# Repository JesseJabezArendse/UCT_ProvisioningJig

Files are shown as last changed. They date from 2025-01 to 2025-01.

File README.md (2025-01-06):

# UCT Provisioning Jig

This repository contains all resources and guides for the UCT Provisioning Jig.

---

### [Raspberry Pi Code/](https://github.com/JesseJabezArendse/UCT_ProvisioningJig/tree/main/Raspberry%20Pi%20Code)
This directory contains the main source code for the Provisioning Jig. 
It includes python scripts for hardware interaction and device programming.

### [PCBs/](https://github.com/JesseJabezArendse/UCT_ProvisioningJig/tree/main/PCB)
Schematics and PCB layouts for the Provisioning Jig and UCT Debugger v2.1.

### [Enclosure/](https://github.com/JesseJabezArendse/UCT_ProvisioningJig/tree/main/Enclosure)
Solidworks files, gcode and Assembly Guidelines for the Enclosure of the Provisioning Jig.

### [Documentation](https://github.com/JesseJabezArendse/UCT_ProvisioningJig/tree/main/Provisioning%20Jig%20v3%20Documentation.pdf)
Guidelines and specifications for using and modifying the Provisioning Jig.

---

## How to use the Provisioning Jig

1. Write the ProvisioningJig_V2J45.IMG file onto a 16GB SD Card using [Win32DiskImager](https://win32diskimager.org/).
2. 3D print the enclosure using the provided [gcode files](https://github.com/JesseJabezArendse/UCT_ProvisioningJig/tree/main/Enclosure/Enclosure%20gcode) and assemble according to the [guide](https://github.com/JesseJabezArendse/UCT_ProvisioningJig/blob/main/Enclosure/Assembly%20Guide.docx).

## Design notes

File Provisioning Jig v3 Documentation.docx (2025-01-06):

# Provisioning Jig v3 Documentation

Project by Jesse Jabez Arendse
Project for UCT EEE Department - Robyn Verrinder & Justin Pead

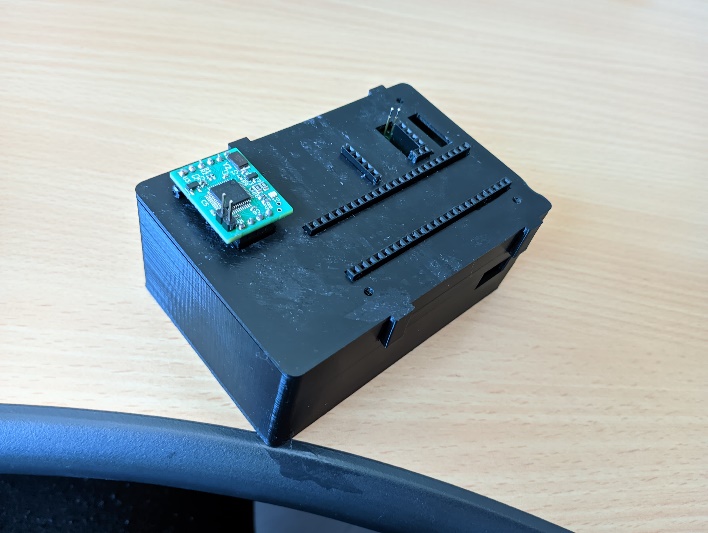
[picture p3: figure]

Host Machine Details:
Raspberry Pi 3B+ with Raspberry Pi OS 64-bit, with 16GB SD Card, SSH and VNC enabled

Username: ProvisioningJig
Password: ProvisioningJig
Hostname: raspberrypi

System Routine:

- On power up, LEDs are lit, indicating that the Pi is still booting up
- Once script starts, STLink is enumerated and LEDs pulse periodically, indicating the Jig is ready (idle mode)
- Plug either device in, orange LED lights up, indicating a device is detected
- Device is provisioned, indicated by STLink LED flashing red-blue (new) or red-green (old)
- Green LED is lit, indicating provisioning is successful and device can be removed

(If STLink LED stopped flashing and no LEDs are lit, provisioning failed, try again or device is faulty)

System Functions:

- Auto login and run provisioning script on startup
- Automatically detect which device is plugged in, and the version
- Flash the device via SWD, with its specific binary file
- Upgrade the STLink to a recent usable version, this step needed to be done with the STSW-LINK007 software package, but has been eliminated details found in the project report

For updates / reproduction:

- main script is located at /Desktop/ProvisioningJig_Code/newMain.py
- binary file selection can be done from the telnet_commands.py file
- use Win32DiskImager to create an .img of the ProvisioningJig’s SD Card, and then PiShrink to compress it (optional, but saves a few GB and time)
- use Win32DiskImager to flash the desired .img file to an SD Card
- assemble the Jig according to the assembly guide

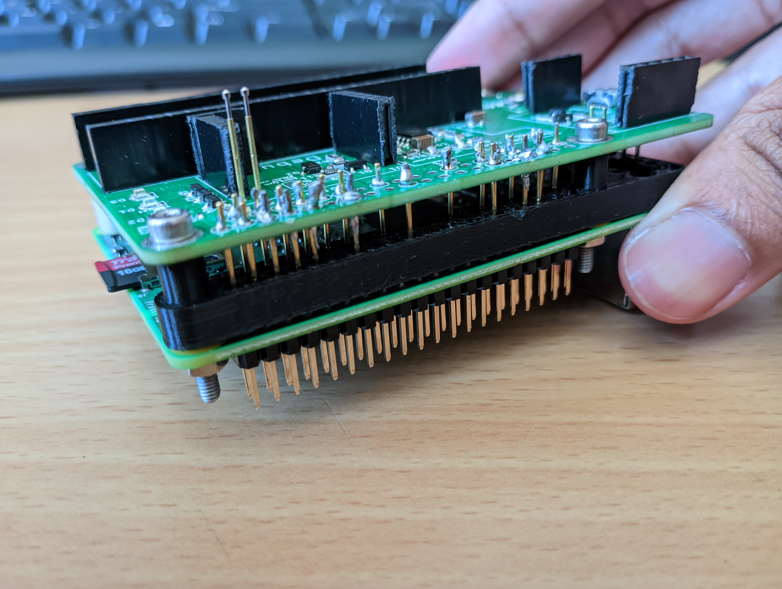
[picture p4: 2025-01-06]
pogos.jpg

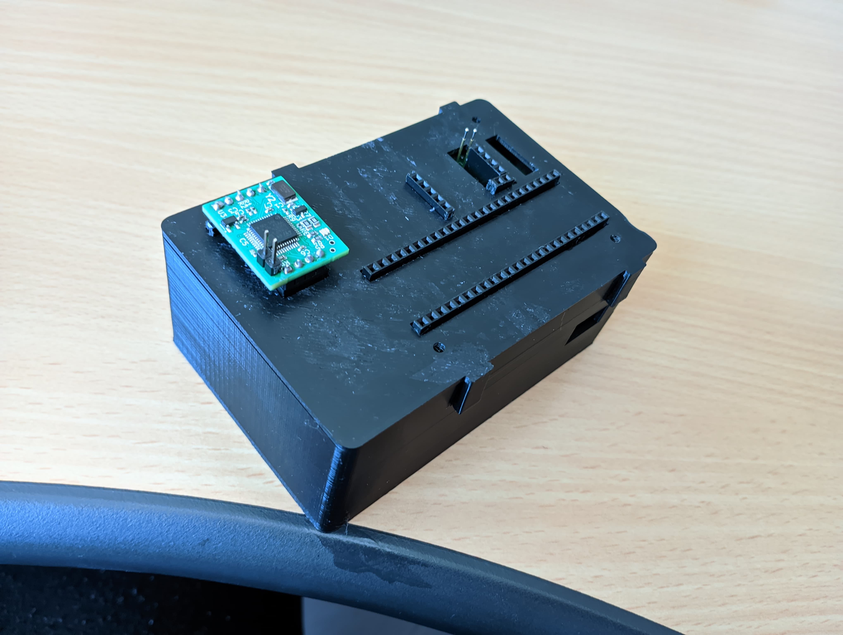
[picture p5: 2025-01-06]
main.jpg

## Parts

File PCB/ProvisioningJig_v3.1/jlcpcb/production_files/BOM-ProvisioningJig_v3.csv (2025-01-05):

Comment | Designator | Footprint | LCSC | Quantity
100u | C7,C9 | C_1206_3216Metric | C15008 | 2
AO3401A | Q2,Q6,Q8 | SOT-23 | C15127 | 3
10k | R12,R13,R17,R18 | R_0805_2012Metric | C17414 | 4
100k | R1,R10,R21,R22,R24,R25,R26,R27,R5,R6,R7,R9 | R_1206_3216Metric | C17900 | 12
1k | R11,R14,R16,R20,R3,R8 | R_0603_1608Metric | C21190 | 6
S8050_SMD | Q1,Q3,Q4,Q5,Q7,Q9 | SOT-23 | C2146 | 6
Yellow | D1,D2 | D_0805_2012Metric | C2296 | 2
Green | D3 | D_0805_2012Metric | C2297 | 1
100 | R15,R19,R2,R23,R4 | R_0402_1005Metric | C25076 | 5
100n | C10,C8 | C_0402_1005Metric | C307331 | 2
Target Button | SW1,SW2 | SW_SPST_TL3342 | C318884 | 2
USB for Debugger | J1,J5 | USB_Conn_JLC_LCSC_C404969 | C404969 | 2
LM393 | U5 | SOIC-8-1EP_3.9x4.9mm_P1.27mm_EP2.29x3mm | C7955 | 1
Target | U3 | STM32F051C6T6 |  | 1
New Version Debugger | U1 | STLINK_UCT |  | 1
ST-Link | U2 | STLINK_UCT |  | 1
POGO USB2- | J7 | P702200045 |  | 1
POGO USB2+ | J6 | P702200045 |  | 1
POGO USB1- | J4 | P702200045 |  | 1
POGO USB1+ | J3 | P702200045 |  | 1
Raspberry_Pi_2_3 | J2 | RASPBERRY_PI_3B |  | 1

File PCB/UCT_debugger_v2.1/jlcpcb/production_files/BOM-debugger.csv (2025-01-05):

Comment | Designator | Footprint | LCSC
X50328MSB2GI | Y2 | RESC5032X135N | C115962
100n | C5,C6,C7 | C_0402_1005Metric_Pad0.74x0.62mm_HandSolder | C1525
10k | R7,R8 | R_0805_2012Metric | C17414
S8050_SMD | Q1 | SOT-23 | C2146
150R | R4,R5,R6 | R_0603_1608Metric | C22808
100 | R3 | R_0402_1005Metric | C25076
1k5 | R1,R9 | R_0402_1005Metric_Pad0.72x0.64mm_HandSolder | C25867
LED_Dual_AKAK | D1 | DUAL_LED_COM_CATH_0606 | C2827309
10p | C1,C2 | C_0402_1005Metric_Pad0.74x0.62mm_HandSolder | C32949
2k | R2 | R_0402_1005Metric_Pad0.72x0.64mm_HandSolder | C4109
1u | C3,C4 | C_0402_1005Metric_Pad0.74x0.62mm_HandSolder | C52923
XC6206PxxxMR | U3 | SOT-23-3 | C5446
STM32F103CBTx | U4 | LQFP-48_7x7mm_P0.5mm | C8304

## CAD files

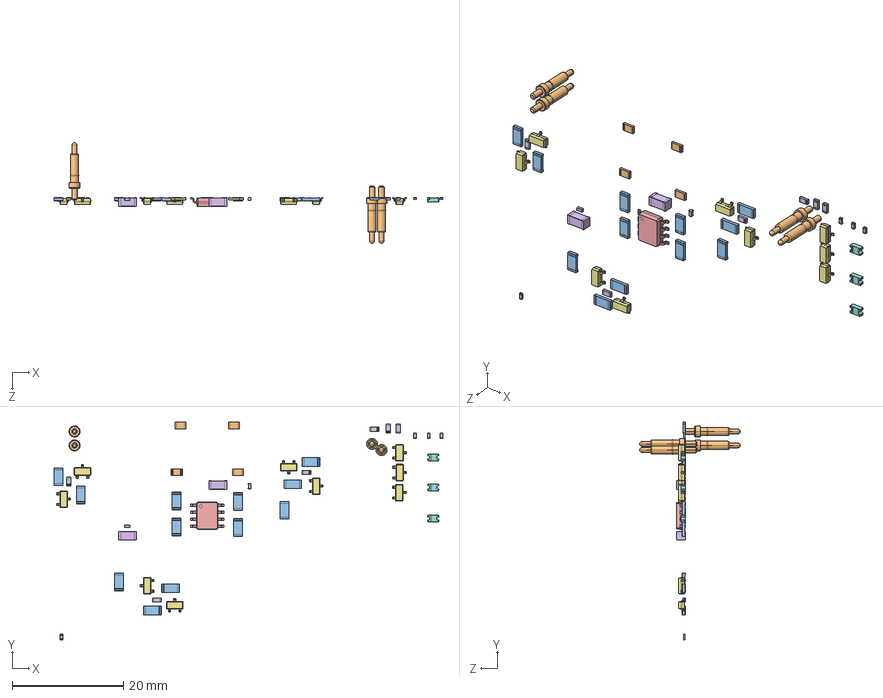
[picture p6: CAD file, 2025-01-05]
Enclosure/Solidworks Model/ProvisioningJig_Board.SLDASM
69.9 x 39.1 x 18.1 mm
R_0603_1608Metric-0.step x 6
R_0805_2012Metric-1.step x 4
R_1206_3216Metric-2.step x 12
R_0402_1005Metric-3.step x 5
SOIC-8-1EP_3.9x4.9mm_P1.27mm_EP2.29x3mm-4.step
C_1206_3216Metric-5.step x 2
SOT_23.step x 9
D_0805.step x 3
C_0402_1005Metric-7.step x 2
P70-2200045-8.step x 4

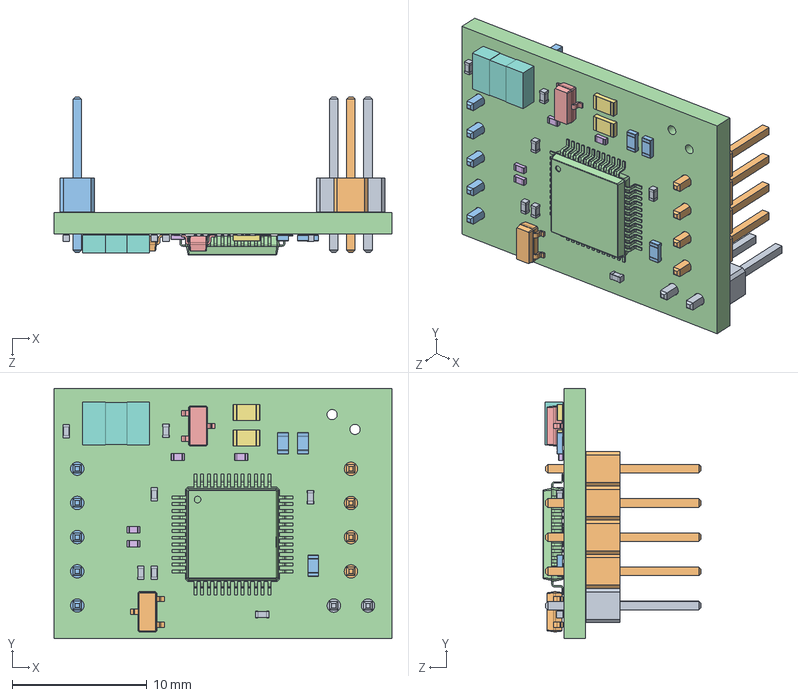
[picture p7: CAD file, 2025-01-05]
Enclosure/Solidworks Model/New_Debugger.SLDASM
25.1 x 18.6 x 11.7 mm
C_0402_1005Metric-7.step x 7
SOT-23-3-1.step
R_0603_1608Metric-0.step x 3
LQFP_48_7x7mm_P05mm.step
SOT_23.step
R_0402_1005Metric-3.step x 4
R_0805_2012Metric-1.step x 2
ASSEMBLY.step
PinHeader_1x02_P254mm_Vertical.step
PinHeader_1x04_P254mm_Vertical.step
PinHeader_1x05_P254mm_Vertical.step
debugger_PCB.step

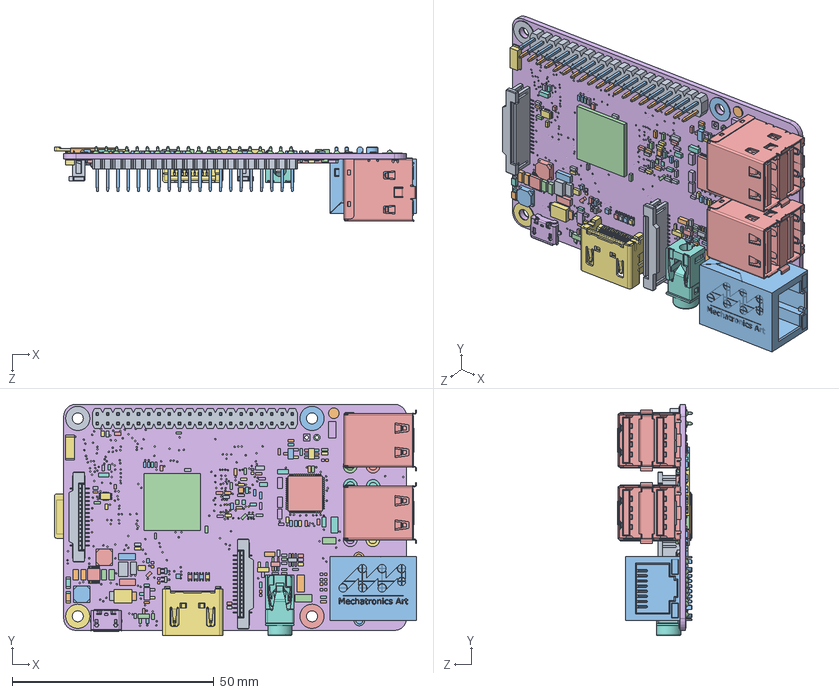
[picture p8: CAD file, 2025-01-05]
Enclosure/Solidworks Model/Raspberry Pi 3.SLDASM
89.6 x 57.3 x 18.6 mm
Raspberry Pi 3157
Raspberry Pi 3242 x 20
Raspberry Pi 3266 x 20
raspberry_pi_3(bar_180_2x20)
MOLEX_672983090 x 2
molex_0473460001
molex_0471510001
PJ-322
te_1-1734248-5 x 2
MOLEX_1040310811
raspberry_pi_B_(RJ45)
Raspberry Pi 312
Raspberry Pi 314
Raspberry Pi 3172
Raspberry Pi 3173
Raspberry Pi 3174
Raspberry Pi 3175
Raspberry Pi 3176
Raspberry Pi 3177
Raspberry Pi 3178
Raspberry Pi 3179
Raspberry Pi 3180
Raspberry Pi 3181
Raspberry Pi 3182
Raspberry Pi 3183
Raspberry Pi 3184
Raspberry Pi 3185
Raspberry Pi 3186
Raspberry Pi 3187
Raspberry Pi 3188
Raspberry Pi 3189
Raspberry Pi 3190
Raspberry Pi 3191
Raspberry Pi 3192
Raspberry Pi 3193
Raspberry Pi 3194
Raspberry Pi 3195
Raspberry Pi 3196
Raspberry Pi 3197
Raspberry Pi 3198
Raspberry Pi 3199
Raspberry Pi 3200
Raspberry Pi 3201
Raspberry Pi 3202
Raspberry Pi 3203
Raspberry Pi 3204
Raspberry Pi 3205
Raspberry Pi 3206
Raspberry Pi 3207
Raspberry Pi 3208
Raspberry Pi 3209
Raspberry Pi 3210
Raspberry Pi 3211
Raspberry Pi 3212
Raspberry Pi 3213
Raspberry Pi 3214
Raspberry Pi 3215
Raspberry Pi 3216
Raspberry Pi 3217
Raspberry Pi 3218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

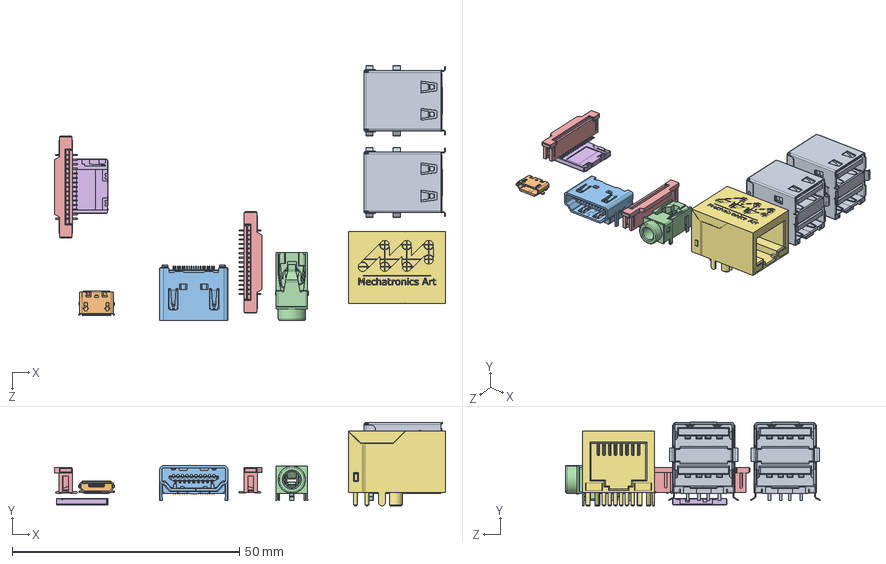
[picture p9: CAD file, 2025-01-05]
Enclosure/Solidworks Model/Rpi components/RPi3_ModelB v1.sldasm
86.1 x 18.5 x 56.1 mm
MOLEX_672983090 x 2
molex_0473460001
molex_0471510001
PJ-322
te_1-1734248-5 x 2
MOLEX_1040310811
raspberry_pi_B_(RJ45)

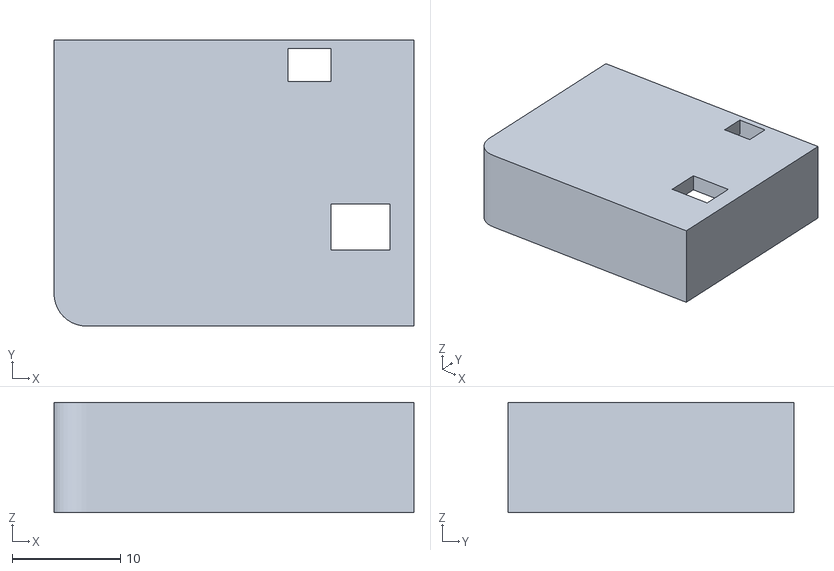
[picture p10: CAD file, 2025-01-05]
Enclosure/Enclosure gcode/STLs/4_STLink_Cover.STL
33.2 x 26.4 x 10.2

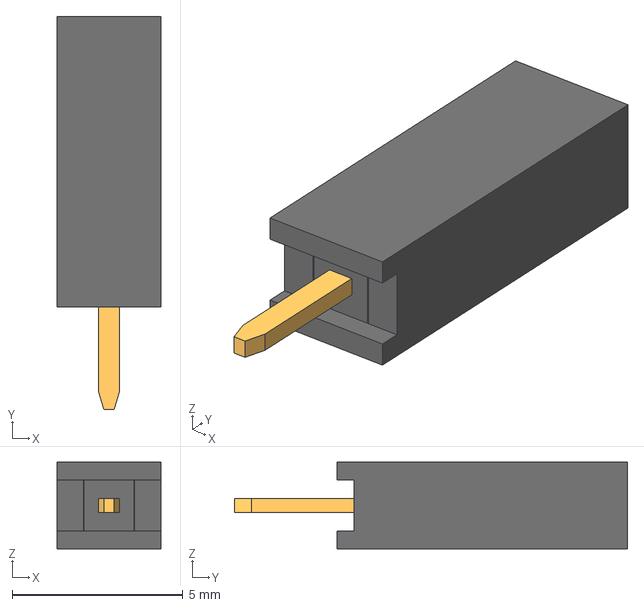
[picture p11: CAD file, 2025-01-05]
Enclosure/Solidworks Model/FemaleHeader.stp
3.04 x 11.5 x 2.54 mm

PCB/ProvisioningJig_v3.1/footprints/raspberry-pi-3-b-plus-mechanical-drawing.dxf
11
5
1
N
K
E
A
13
R 007-AG0046
CMIIT ID: 2018AJ2147
KCC: R-CMM-P2R-RPI3P
IFETEL: RCPRARA18-1020
IN CHINA
PCB MADE
PEN
IC: 20953-RPI3P
FCC ID: 2ABCB-RPI3BP
Licensed from
Proant AB
Uses technology
PoE
c Raspberry Pi 2017
Raspberry Pi 3 Model B
MICRO SD CARD
HDMI
BOTOM LEGEND
BOTTOM ASSEMBLY
TOP LEGEND
TOP ASSEMBLY
Made in the UK
A/V
GPIO
USB
ETHERNET
PWR IN
DISPLAY
CAMERA
RUN
ACT
PWR

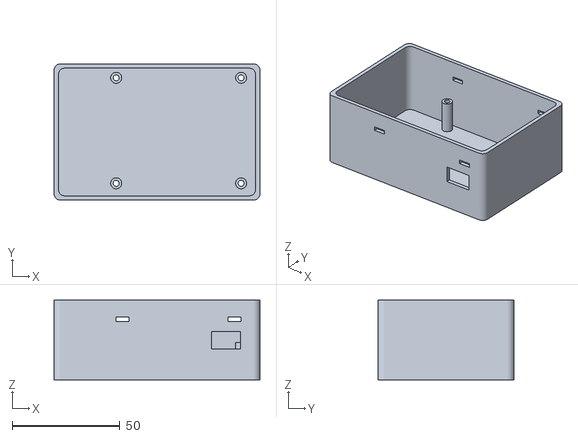
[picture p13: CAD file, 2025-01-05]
Enclosure/Enclosure gcode/STLs/2_Enclosure_Base.STL
95.6 x 63.3 x 37.1

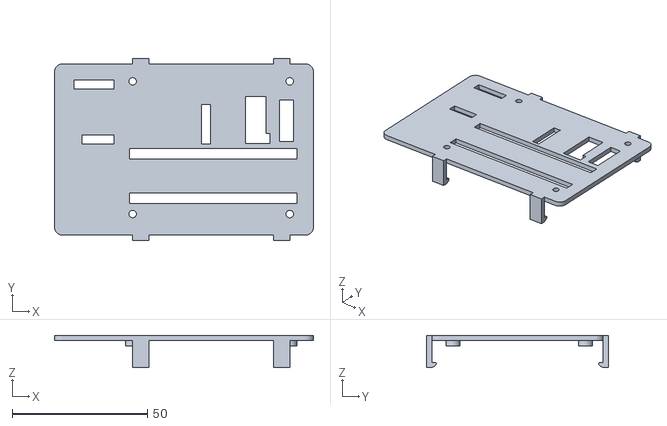
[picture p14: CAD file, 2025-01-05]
Enclosure/Enclosure gcode/STLs/3_Enclosure_Lid.STL
95.6 x 67.3 x 12.0

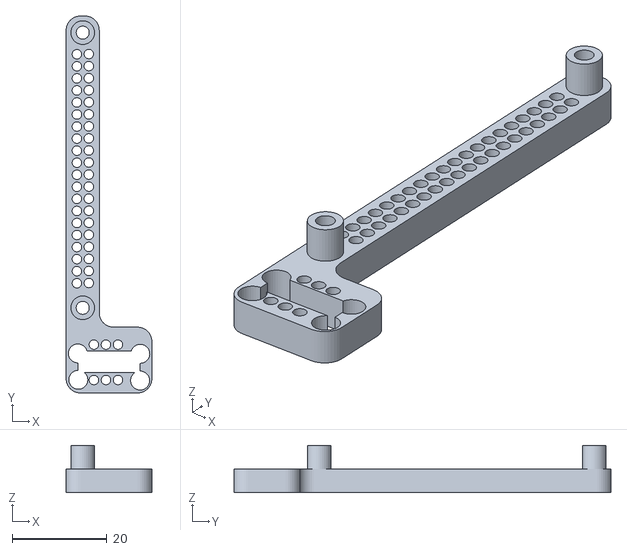
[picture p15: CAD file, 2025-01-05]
Enclosure/Enclosure gcode/STLs/1_POGO Supports.STL
18.1 x 79.5 x 10.0

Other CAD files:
Enclosure/Solidworks Model/Rpi components/Raspberry Pi 3143.sldprt
Enclosure/Solidworks Model/Rpi components/Raspberry Pi 3226.sldprt
Enclosure/Solidworks Model/Rpi components/Raspberry Pi 3318.sldprt
Enclosure/Solidworks Model/Enclosure_Lid.SLDPRT
Enclosure/Solidworks Model/Rpi components/Raspberry Pi 3162.sldprt
Enclosure/Solidworks Model/Rpi components/Raspberry Pi 3358.sldprt
Enclosure/Solidworks Model/POGO Supports.SLDPRT
Enclosure/Solidworks Model/Rpi components/Raspberry Pi 3187.sldprt
Enclosure/Solidworks Model/Enclosure_Base.SLDPRT
Enclosure/Solidworks Model/M2.5 Hex Screw v2.step
Enclosure/Solidworks Model/M2.5 Nut v2.step
Enclosure/Solidworks Model/Pogo_pin_P75-E2.stp
Enclosure/Solidworks Model/Rpi components/HANRUN2_HR911105A.sldprt
Enclosure/Solidworks Model/Rpi components/MOLEX_1040310811.sldprt
Enclosure/Solidworks Model/Rpi components/MOLEX_672983090.sldprt
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

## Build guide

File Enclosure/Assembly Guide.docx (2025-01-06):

# Provisioning Jig v3 Assembly Guide

Project by Jesse Jabez Arendse
Project for UCT EEE Department - Robyn Verrinder & Justin Pead

Assembly Considerations:

- Optional STLink Cap to further prevent accidental shorts
- Enclosure is self-locking
- 2x 10mm spacers are needed between the PCBs
- 2x M2.5 Bolts & Nuts should be used to secure the PCBs, or M2.5 Rods can be used to connect the Jig and the enclosure for table mounting

Assembly Guidelines:

Solder POGO pins and headers ONLY for each circled throughhole

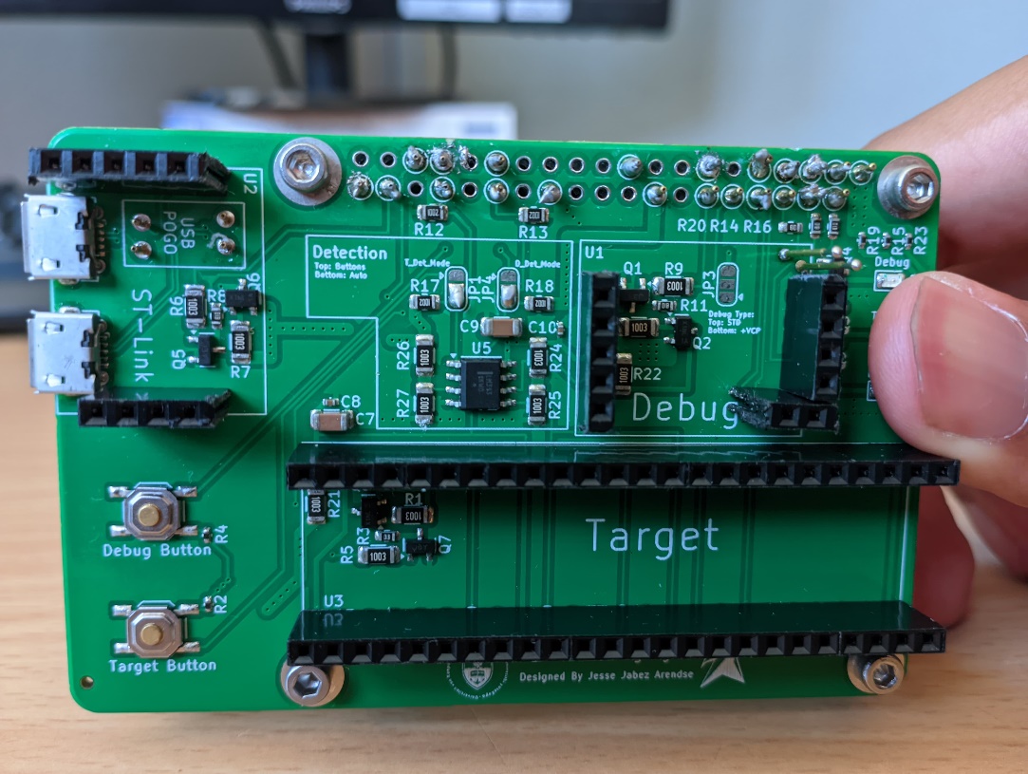
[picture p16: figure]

Place M2.5 Bolts through the PCB holes, POGO Support 3D print holes while ensuring each pin goes through their specific hole, and RPI. Secure with Nuts

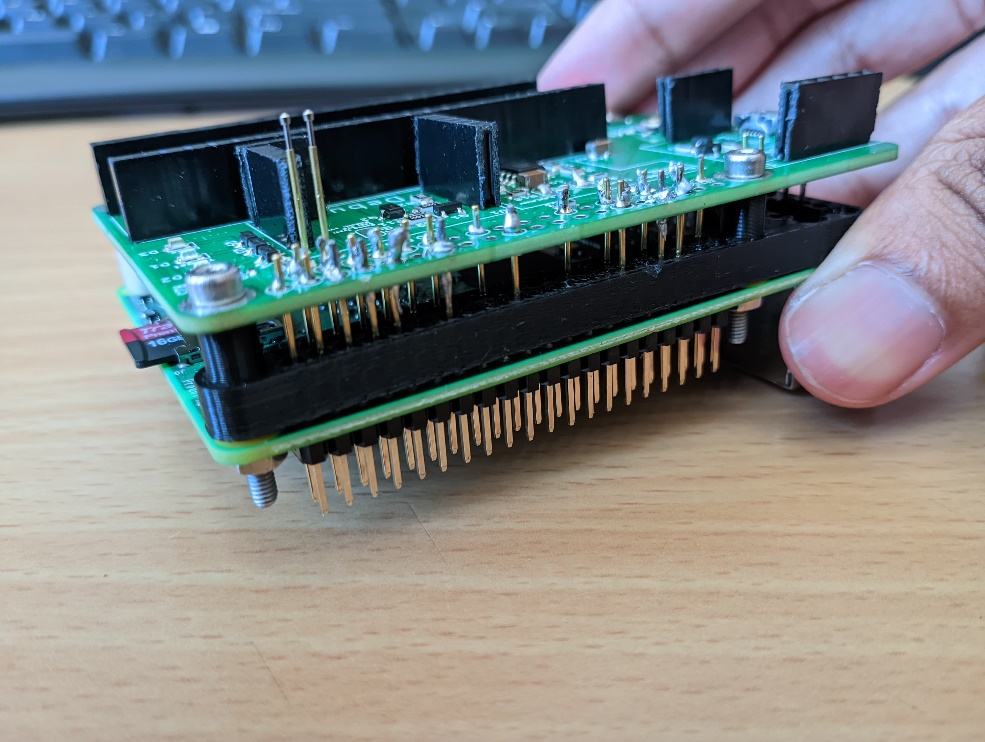
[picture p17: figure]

The enclosure base has slots for the excess bolt shafts to pass through, which also aligns and secures the PCBs.

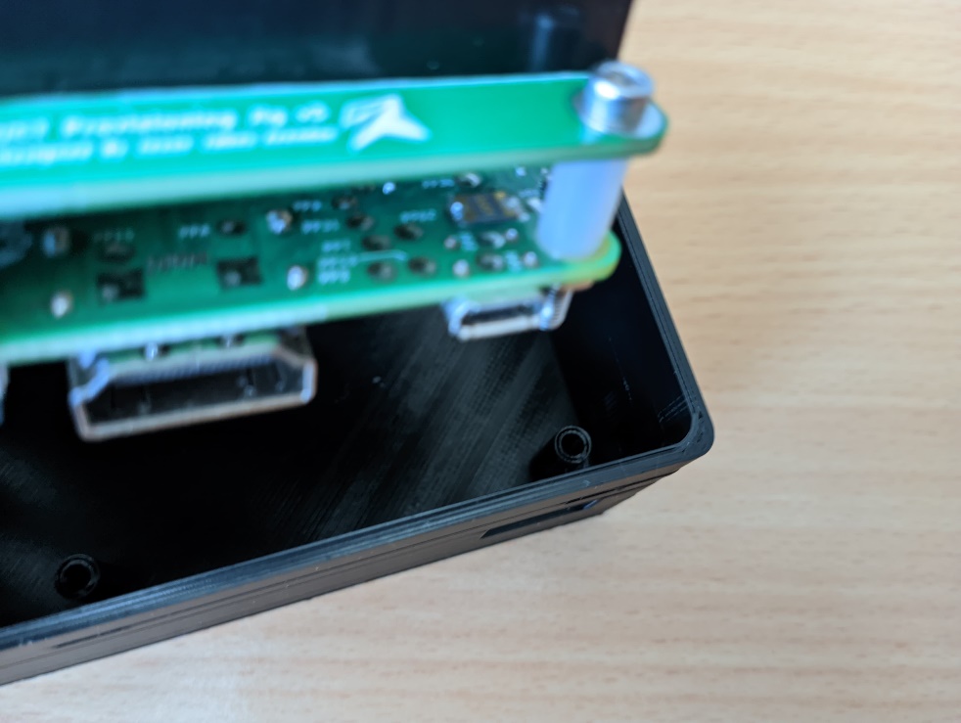
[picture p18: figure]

Complete the Jig with the lid, making sure the headers pass through the gaps of the lid and the protruding bits lock the enclosure. It’s quite tight and needs some force to assemble and dissemble. Plug in an already programmed debugger into the STLink slot to complete the Provisioning Jig Assembly.

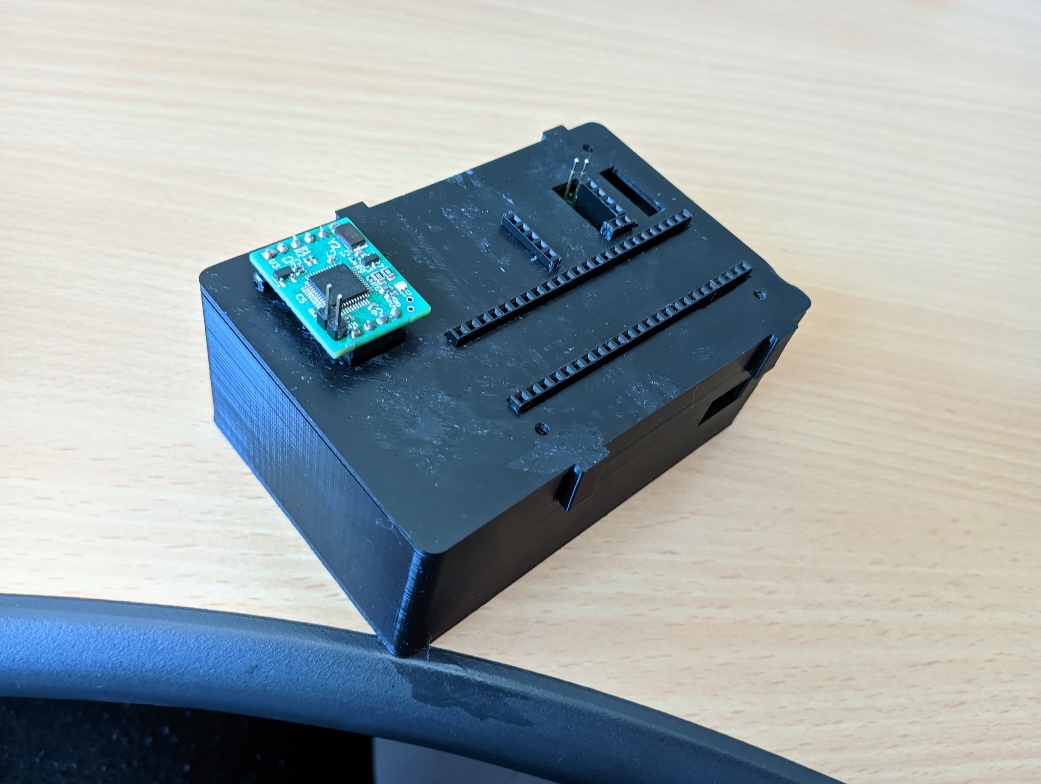
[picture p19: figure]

An assembly video can be found on the gitrepo as well.

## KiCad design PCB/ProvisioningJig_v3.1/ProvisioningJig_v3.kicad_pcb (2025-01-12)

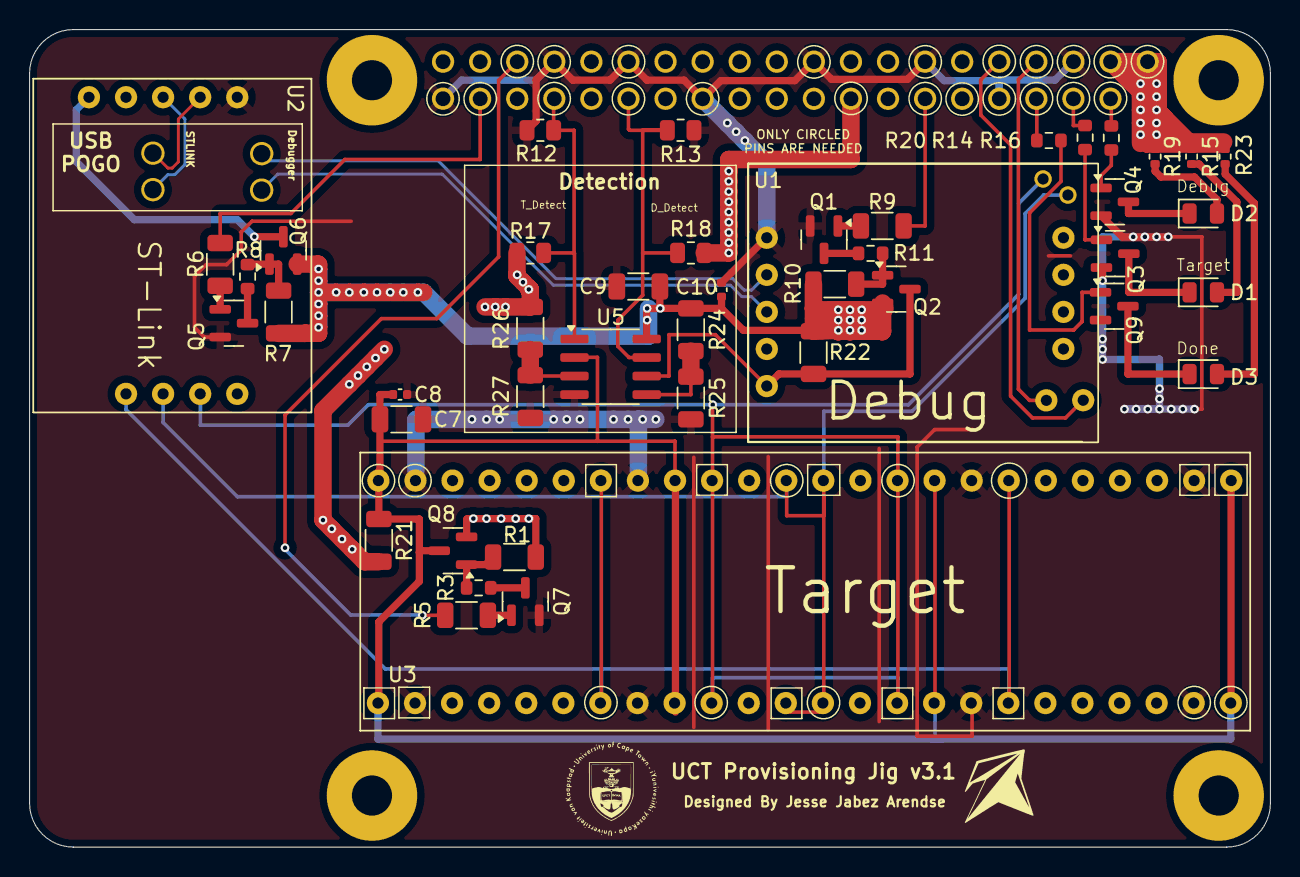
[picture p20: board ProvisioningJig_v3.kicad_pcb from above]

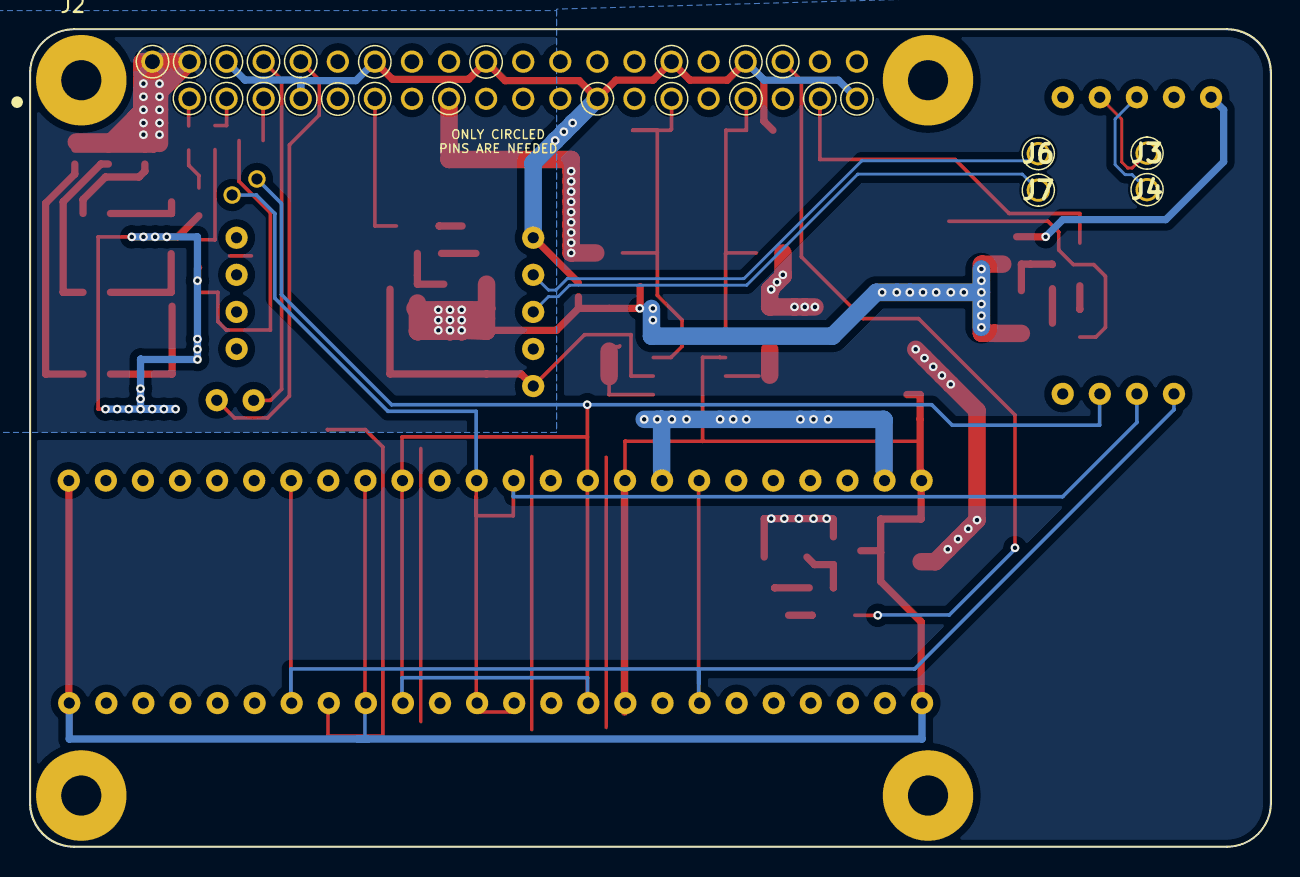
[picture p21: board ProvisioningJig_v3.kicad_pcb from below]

Board: 2 copper layers, 85.0 x 56.0 mm, 50 parts (5 on the bottom side), 43 nets.

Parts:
C7, C9: 100u; C_1206_3216Metric
C8, C10: 100n; C_0402_1005Metric
D1, D2: Yellow; D_0805_2012Metric
D3: Green; D_0805_2012Metric
J2: Raspberry_Pi_2_3; RASPBERRY_PI_3B
J3: POGO USB1+; P702200045
J4: POGO USB1-; P702200045
J6: POGO USB2+; P702200045
J7: POGO USB2-; P702200045
Q1, Q3, Q4, Q5, Q7, Q9: S8050_SMD; SOT-23
Q2, Q6, Q8: AO3401A; SOT-23
R1, R5, R6, R7, R9, R10, R21, R22, R24, R25, R26, R27: 100k; R_1206_3216Metric
R3, R8, R11, R14, R16, R20: 1k; R_0603_1608Metric
R12, R13, R17, R18: 10k; R_0805_2012Metric
R15, R19, R23: 100; R_0402_1005Metric
U1: New Version Debugger; STLINK_UCT
U2: ST-Link; STLINK_UCT
U3: Target; STM32F051C6T6
U5: LM393; SOIC-8-1EP_3.9x4.9mm_P1.27mm_EP2.29x3mm

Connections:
+3V3: J2.17 (3V3), Q8.2 (S), R1.1, R17.2, R18.2, R21.1, R26.1
+5V: C9.1, C10.1, J2.2 (5V), J2.4 (5V), Q2.2 (S), Q6.2 (S), R7.1, R10.1, R15.2, R19.2, R22.1, R23.2, R24.1, U5.8 (V+)
/D_Det_Bias: R24.2, R25.1, U5.5 (+)
/D_SWCLK: U1.11 (TP2), U2.7 (T_SWCLK), U3.12 (PA2), U3.13 (PA3), U3.36 (PF7), U3.37 (PA14)
/D_SWIO: U1.10 (TP1), U2.8 (T_SWDIO), U3.10 (PA0), U3.15 (PA5), U3.34 (PA13), U3.39 (PB3)
/Debug_Detect: J2.29 (GCLK1/GPIO5), R13.2, R18.1, U5.7
/Debugger_PWR: Q2.3 (D), R22.2, U1.1 (5V_USB), U5.6 (-)
/NRST: U2.6 (T_NRST), U3.7 (NRST), U3.18 (PB0), U3.31 (PA10), U3.42 (PB6)
/RPI_Debug_EN: J2.13 (GPIO27), R9.1
/RPI_STLINK_EN: J2.37 (GPIO26), R6.1
/RPI_Target_EN: J2.36 (GPIO16), R5.1
/Raspberry Pi IOs/D_Yellow: J2.3 (SDA/GPIO2), R16.1
/Raspberry Pi IOs/Green: J2.7 (GCLK0/GPIO4), R20.1
/Raspberry Pi IOs/T_Yellow: J2.5 (SCL/GPIO3), R14.1
/STLink_PWR: Q6.3 (D), U2.1 (5V_USB)
/STLink_Rx: J2.8 (GPIO14/TXD), U1.12 (Rx)
/STLink_Tx: J2.10 (GPIO15/RXD), U1.13 (Tx)
/T_Det_Bias: R26.2, R27.1, U5.3 (+)
/Target_Detect: J2.33 (PWM1/GPIO13), R12.2, R17.1, U5.1
/Target_PWR: C7.1, C8.1, Q8.3 (D), R21.2, U3.1 (VBAT), U3.9 (V+), U3.16 (PA6), U3.24 (V+), U3.25 (PB12), U3.33 (PA12), U3.40 (PB4), U3.48 (V+), U5.2 (-)
/USB1+: J3.1, U2.4 (USB_DP)
/USB1-: J4.1, U2.3 (USB_DM)
/USB2+: J6.1, U1.4 (USB_DP)
/USB2-: J7.1, U1.3 (USB_DM)
GND: C7.2, C8.2, C9.2, C10.2, J2.6 (GND), J2.9 (GND), J2.14 (GND), J2.20 (GND), J2.25 (GND), J2.30 (GND), J2.34 (GND), J2.39 (GND), Q1.2 (E), Q3.2 (E), Q4.2 (E), Q5.2 (E), Q7.2 (E), Q9.2 (E), R12.1, R13.1, R25.2, R27.2, U1.5 (GND), U2.5 (GND), U3.2 (PC13), U3.8 (GND), U3.17 (PA7), U3.23 (GND), U3.26 (PB13), U3.32 (PA11), U3.41 (PB5), U3.47 (GND), U5.4 (V-)
unnamed: D1.2 (A), R15.1
unnamed: D1.1 (K), Q3.3 (C)
unnamed: D2.2 (A), R19.1
unnamed: D2.1 (K), Q4.3 (C)
unnamed: D3.2 (A), R23.1
unnamed: D3.1 (K), Q9.3 (C)
unnamed: Q1.1 (B), R9.2
unnamed: Q1.3 (C), R11.1
unnamed: Q2.1 (G), R10.2, R11.2
unnamed: Q3.1 (B), R14.2
unnamed: Q4.1 (B), R16.2
unnamed: Q5.1 (B), R6.2
unnamed: Q5.3 (C), R8.1
unnamed: Q6.1 (G), R7.2, R8.2
unnamed: Q7.1 (B), R5.2
unnamed: Q7.3 (C), R3.1
unnamed: Q8.1 (G), R1.2, R3.2
unnamed: Q9.1 (B), R20.2

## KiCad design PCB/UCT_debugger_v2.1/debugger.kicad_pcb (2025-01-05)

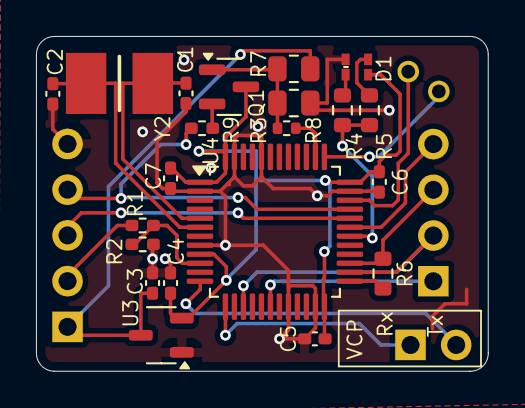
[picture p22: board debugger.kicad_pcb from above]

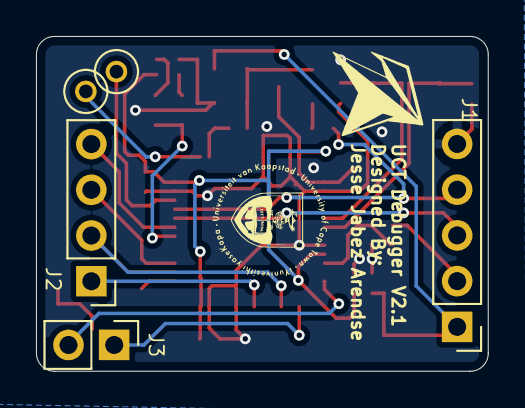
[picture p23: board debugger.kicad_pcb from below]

Board: 2 copper layers, 25.1 x 18.6 mm, 26 parts (5 on the bottom side), 24 nets.

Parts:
C1, C2: 10p; C_0402_1005Metric_Pad0.74x0.62mm_HandSolder
C3, C4: 1u; C_0402_1005Metric_Pad0.74x0.62mm_HandSolder
C5, C6, C7: 100n; C_0402_1005Metric_Pad0.74x0.62mm_HandSolder
D1: LED_Dual_AKAK; DUAL_LED_COM_CATH_0606
J1: Conn_01x05_Pin; PinHeader_1x05_P2.54mm_Vertical
J2: Conn_01x04_Pin; PinHeader_1x04_P2.54mm_Vertical
J3: Conn_01x02_Pin; PinHeader_1x02_P2.54mm_Vertical
Q1: S8050_SMD; SOT-23
R1, R9: 1k5; R_0402_1005Metric_Pad0.72x0.64mm_HandSolder
R2: 2k; R_0402_1005Metric_Pad0.72x0.64mm_HandSolder
R3: 100; R_0402_1005Metric
R4, R5, R6: 150R; R_0603_1608Metric
R7, R8: 10k; R_0805_2012Metric
TP1, TP2: TestPoint; TestPoint_Pad_D2.0mm
U3: XC6206PxxxMR; SOT-23-3
U4: STM32F103CBTx; LQFP-48_7x7mm_P0.5mm
Y2: X50328MSB2GI; RESC5032X135N

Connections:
+3V3: C4.1, C5.1, C6.1, C7.1, D1.1 (A1), Q1.3 (C), U3.2 (VO), U4.1 (VBAT), U4.9 (VDDA), U4.24 (VDD), U4.36 (VDD), U4.48 (VDD)
+5V: C3.1, J1.1, R7.2, U3.3 (VI)
/D_SWCLK: TP2.1, U4.37 (PA14)
/D_SWDIO: TP1.1, U4.34 (PA13)
/LED_STLINK: R4.2, R5.1, U4.30 (PA9)
/STLink_Rx: J3.1, U4.13 (PA3)
/STLink_Tx: J3.2, U4.12 (PA2)
/T_RST: J2.1, U4.18 (PB0)
/T_SWCLK: J2.2, U4.15 (PA5), U4.26 (PB13)
/T_SWDIO: J2.3, R6.1, U4.27 (PB14)
/T_SWO: J2.4, U4.31 (PA10)
/T_Voltage: J1.2, R1.1
/USB_DM: J1.3, U4.32 (PA11)
/USB_DP: J1.4, R9.2, U4.33 (PA12)
/USB_re_enum: R3.2, U4.38 (PA15)
GND: C1.2, C2.2, C3.2, C4.2, C5.2, C6.2, C7.2, D1.4 (K2), J1.5, R2.1, R8.1, U3.1 (GND), U4.2 (PC13), U4.8 (VSSA), U4.20 (PB2), U4.23 (VSS), U4.35 (VSS), U4.44 (BOOT0), U4.47 (VSS)
unnamed: D1.3 (A2), R5.2
unnamed: D1.2 (K1), R4.1
unnamed: Q1.1 (B), R3.1, R7.1, R8.2
unnamed: Q1.2 (E), R9.1
unnamed: R1.2, R2.2, U4.10 (PA0)
unnamed: R6.2, U4.25 (PB12)
unnamed: C1.1, U4.5 (PD0), Y2.1
unnamed: C2.1, U4.6 (PD1), Y2.2

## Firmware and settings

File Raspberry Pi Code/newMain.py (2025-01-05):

from openOCD_commands import start_openOCD_for_debugger, start_openOCD_for_target
from telnet_commands import *
from upgrade_stlink import *
from power_commands import *
from led_commands import *
import time

print("Hello from UCT EEE ProvisioningJig v3! - STLink version V2J45")
print("Author: Jesse Jabez Arendse")
print("Date Modified: 18/12/2024")
print("python script: /home/ProvisioningJig/Desktop/ProvisioningJig_Code/newMain.py")
print("username and pwd are ProvisioningJig")

# detection pins
DEBUG_DET = 5
TARGET_DET = 13

areLEDsON = False
new_stlink = 0

def check_if_new_debugger():
    time.sleep(4)
    target_model = "sda"
    try:
        # Spawn a shell process
        lsblk = pexpect.spawn("lsblk -o NAME", encoding="utf-8")
        
        # Send the lsblk command
        lsblk.sendline("lsblk -o NAME")
        
        # Wait for the command to complete
        lsblk.expect(pexpect.EOF)
        
        # Get the full output of the command
        output = lsblk.before
        
        # Count occurrences of the target model
        count = 0
        for line in output.splitlines():
            if target_model.lower() in line.lower():  # Case-insensitive check
                count += 1
        
        # Return True if there are 2 or more instances
        return count
    except pexpect.ExceptionPexpect as e:
        print(f"Error running lsblk: {e}")
        return False

def debug_detected():
    all_off()
    logging.info(f"Debugger Detected!")
    time.sleep(2)
    debug_LED(ON)
    time.sleep(2)
    provision_debugger()
    return None

def target_detected():
    all_off()
    logging.info(f"Target Detected!")
    time.sleep(2)
    target_LED(ON)
    time.sleep(2)
    provision_target()
    return None

def setup_Detections():
    GPIO.setmode(GPIO.BCM)  # Use BCM pin numbering
    GPIO.setup(DEBUG_DET,  GPIO.IN)
    GPIO.setup(TARGET_DET, GPIO.IN)
    return None

def provision_debugger():
    try:
        all_off()
        STLink_power(ON)
        debug_LED(ON)
        Debug_power(ON)

        with start_openOCD_for_debugger() as OCD_success:
            if OCD_success:
                flash_debugger(NEW_DEBUGGER)
            else:
                all_off()
        Debug_power(OFF)
        STLink_power(OFF)
        time.sleep(0.2)
        Debug_power(ON)
        STLink_power(ON)
        curr_num_debuggers = check_if_new_debugger()
        if curr_num_debuggers != new_stlink + 1:
            logging.info(f"Debugger is actually old")
            with start_openOCD_for_debugger() as OCD_success:
                if OCD_success:
                    flash_debugger(OLD_DEBUGGER)
                else:
                    all_off()
        all_off()
        done_LED(ON)

    except TypeError as e:
        print(f"An error occurred: {e}")
        all_off()  # Ensure everything is turned off on error

    finally:
        print("Provisioning complete.")

    return None
    
def provision_target():
    try:
        all_off()
        STLink_power(ON)
        Target_power(ON)

        with start_openOCD_for_target() as OCD_success:
            if OCD_success:
                target_LED(ON)
                flash_target()
                all_off()
                done_LED(ON)
            else:
                all_off()
        time.sleep(8)

    except TypeError as e:
        print(f"An error occurred: {e}")
        all_off()  # Ensure everything is turned off on error

    finally:
        pass
        print("Provisioning complete.")

    return None

def all_off():
    LEDs(OFF)
    STLink_power(ON)
    Target_power(OFF)
    Debug_power(OFF)
    return None

def check_pins():
    debug_state = GPIO.input(DEBUG_DET)  # Read DEBUG_DET pin
    target_state = GPIO.input(TARGET_DET)  # Read TARGET_DET pin
    print(f"DEBUG_DET: {'HIGH' if debug_state else 'LOW'}, TARGET_DET: {'HIGH' if target_state else 'LOW'}")
    return [debug_state , target_state]

def idleIndicate():
    global areLEDsON
    if areLEDsON:
        LEDs(OFF)
        areLEDsON = False
    else:
        LEDs(ON)
        areLEDsON = True
    return None

def main():
    setup_Detections()

    while True:
        all_off()
        time.sleep(0.5)  # Poll every 0.5 seconds
        [debug_state,target_state] = check_pins()
        if debug_state:
            debug_detected() # do the things
            while debug_state: 
                [debug_state,target_state] = check_pins() # wait until debugger is disconnected
                time.sleep(0.2)
            time.sleep(1)
            all_off()
        elif target_state:
            target_detected() # do the things
            while target_state: 
                [debug_state,target_state] = check_pins() # wait until debugger is disconnected
                time.sleep(0.2)
            time.sleep(1)
            all_off()
        else:
            provision_target() # polls cause target detection doesnt work

        idleIndicate()
    return None

if __name__ == "__main__":
    all_off()
    STLink_power(ON)
    new_stlink = check_if_new_debugger()
    if new_stlink == 1:
        logging.info(f"STLink = New Debugger plugged")
    if new_stlink == 0:
        logging.info(f"STLink = Old Debugger plugged")
    main()
    

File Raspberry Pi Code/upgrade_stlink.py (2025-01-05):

import json
import usb.core
import usb.util
import time
import sys

def progress_bar(current, total, bar_length=40):
    fraction = current / total
    arrow = '█' * int(fraction * bar_length)
    spaces = ' ' * (bar_length - len(arrow))
    
    sys.stdout.write(f'\rProgress: |{arrow}{spaces}| {int(fraction * 100)}%')
    sys.stdout.flush()


# Function to send data
def send_data(dev, capdata_bytes):
    try:
        dev.write(0x02, capdata_bytes, timeout=1000)
        # print(f"Sent capdata: {capdata_bytes}")
    except usb.core.USBError as e:
        print(f"Failed to send packet: {e}")
        exit()

# Function to receive data
def receive_data(dev):
    try:
        received_data = dev.read(0x81, 64, timeout=1000)
        # print(f"Received raw data: {received_data}")
        return received_data
    except usb.core.USBError as e:
        print(f"Failed to receive data: {e}")
        exit()
        return None

def makeUpgradeable():
    print("Making ST-Link Upgradable, please wait")

    # Find your USB device
    dev = usb.core.find(idVendor=0x0483, idProduct=0x3748)
    if dev is None:
        raise ValueError("Device not found")

    dev.set_configuration()

    # Load your JSON file
    with open('upgrade_std_old_again.json', 'r') as f:
        datas = json.load(f)

    # Track the previous packet time
    previous_time = None

    # Process each packet
    index = 0
    for data in datas:
        index = index + 1
        progress_bar(index, len(datas))
        current_time = float(data["_source"]["layers"]["frame"]["frame.time_epoch"])

        if previous_time:
            # Calculate the time delay and wait
            time_delta = current_time - previous_time
            time.sleep(time_delta)
        previous_time = current_time

        usb_layer = data["_source"]["layers"]["usb"]
        
        # Check transfer type
        transfer_type = usb_layer.get("usb.transfer_type", "0x03")
        
        # Check if 'usb.capdata' key exists
        if "usb.capdata" in data["_source"]["layers"]:
            capdata_hex = data["_source"]["layers"]["usb.capdata"]
            capdata_bytes = bytes.fromhex(capdata_hex.replace(":", ""))
            
            # Check direction and transfer type
            direction = int(usb_layer["usb.irp_info_tree"]["usb.irp_info.direction"], 16)
            if direction == 0 and transfer_type == "0x03":
                # Out data - send data to device
                send_data(dev, capdata_bytes)
            elif direction == 1 and transfer_type == "0x03":
                # In data - receive data from device
                receive_data(dev)
            else:
                print(f"Skipping packet with unknown type: {transfer_type}")
        else:
            pass
            # print("No 'usb.capdata' key found, skipping entry.")

    return None

def upgradeToNew():
    print("Upgrading ST-Link to V2J45S0, please wait again")

    # Find your USB device
    dev = usb.core.find(idVendor=0x0483, idProduct=0x3748)
    if dev is None:
        raise ValueError("Device not found")

    dev.set_configuration()

    # Load your JSON file
    with open('upgrade_std_new_again.json', 'r') as f:
        datas = json.load(f)

    # Track the previous packet time
    previous_time = None

    # Process each packet
    index = 0
    for data in datas:
        index = index + 1
        progress_bar(index, len(datas))
        current_time = float(data["_source"]["layers"]["frame"]["frame.time_epoch"])

        if previous_time:
            # Calculate the time delay and wait
            time_delta = current_time - previous_time
            time.sleep(time_delta)
        previous_time = current_time

        usb_layer = data["_source"]["layers"]["usb"]
        
        # Check transfer type
        transfer_type = usb_layer.get("usb.transfer_type", "0x03")
        
        # Check if 'usb.capdata' key exists
        if "usb.capdata" in data["_source"]["layers"]:
            capdata_hex = data["_source"]["layers"]["usb.capdata"]
            capdata_bytes = bytes.fromhex(capdata_hex.replace(":", ""))
            
            # Check direction and transfer type
            direction = int(usb_layer["usb.irp_info_tree"]["usb.irp_info.direction"], 16)
            if direction == 0 and transfer_type == "0x03":
                # Out data - send data to device
                send_data(dev, capdata_bytes)
            elif direction == 1 and transfer_type == "0x03":
                # In data - receive data from device
                receive_data(dev)
            else:
                print(f"Skipping packet with unknown type: {transfer_type}")
        else:
            pass
            # print("No 'usb.capdata' key found, skipping entry.")



if __name__ == "__main__":
    makeUpgradeable()

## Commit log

2025-01-05 added directories
    folders for each component of the jig
    [1_POGO Supports.STL, 2_Enclosure_Base.STL, 3_Enclosure_Lid.STL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]
2025-01-05 Added RPI Code
    RPI Code
    [100ask-openjtag.cfg, 8devices-lima.cfg, actux3.cfg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]
2025-01-06 added raspberry pi code
    [1_POGO Supports.STL, 2_Enclosure_Base.STL, 3_Enclosure_Lid.STL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]
2025-01-06 modified provisioning jig code
    [100ask-openjtag.cfg, 8devices-lima.cfg, actux3.cfg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]
2025-01-12 fixed target slot
    [ProvisioningJig_v3.kicad_pcb]
